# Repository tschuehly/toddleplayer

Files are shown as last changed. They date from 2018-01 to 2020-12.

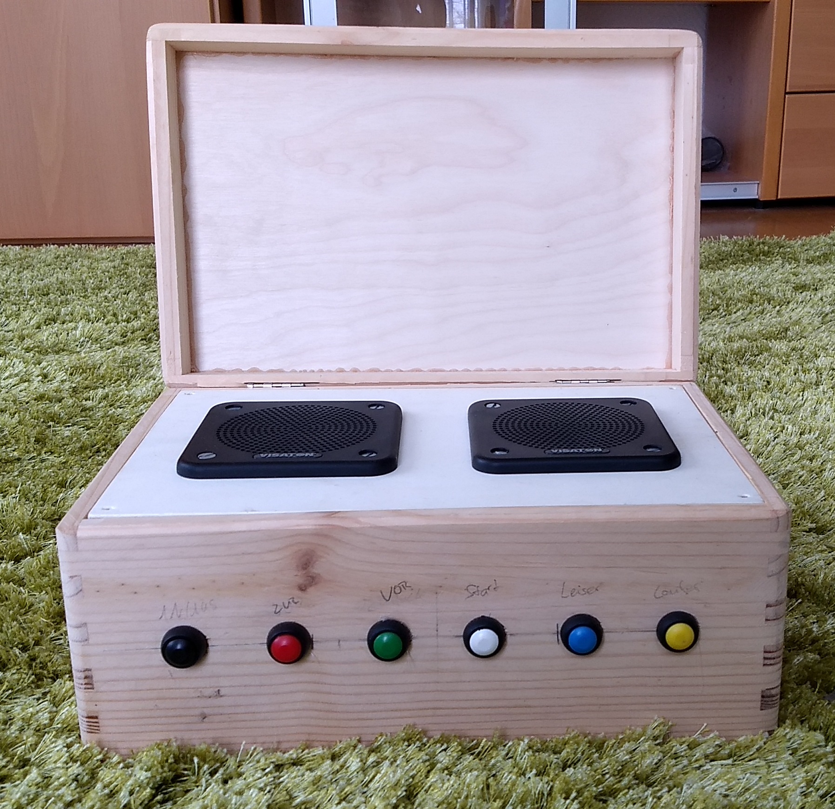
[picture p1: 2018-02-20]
img/front.jpg

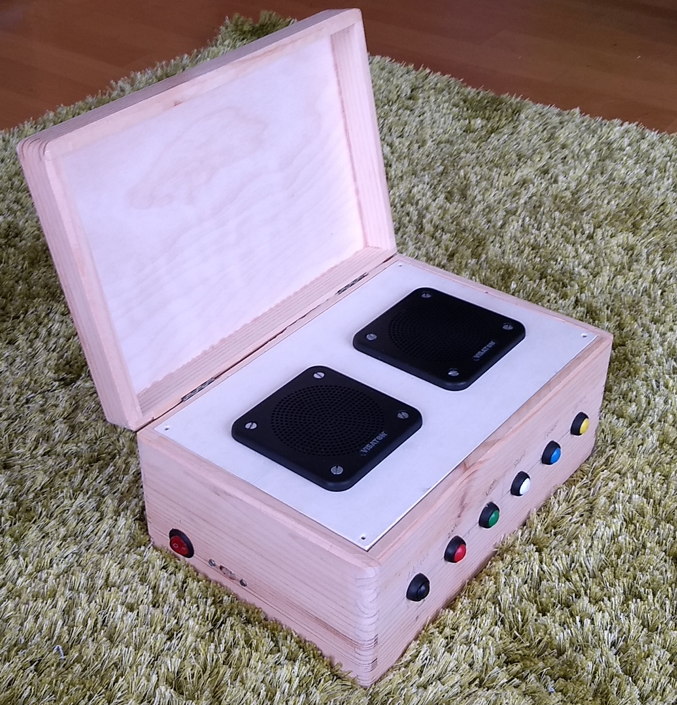
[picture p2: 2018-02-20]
img/side.jpg

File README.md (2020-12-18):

# toddleplayer
toddleplayer is the manual and a bunch of scripts to create an MP3 and Spotify Player controlled through RFID Tags and GPIO Buttons.

## Hardware

Required:

* A [Raspberry Pi](https://www.raspberrypi.org/products/): I'm using a Pi Zero W

* DAC: You can either use a [pHAT DAC 15€](https://shop.pimoroni.com/products/phat-dac)
or a [PCM5102A 3€](https://www.aliexpress.com/item/1Pcs-PCM5102A-DAC-Sound-Card-Board-pHAT-3-5mm-Stereo-Jack-24-Bits-Digital-Audio-Module/32836159429.html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)

* Any kind of casing: [Wooden Box](http://www.ebay.de/itm/ZWEIERGRUPPE-EINFACHES-HOLZ-HOLZKISTE-TRUNK-OHNE-GRIFFE-FUR-SERVIETTEN/152320770330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)

* A few push buttons: [Push Buttons](https://www.ebay.de/itm/152295745935?_trksid=p2060353.m2749.l2649&ssPageName=STRK%3AMEBIDX%3AIT)

* A Digital Audio Amplifier:  [PAM8403](https://www.aliexpress.com/store/product/MCIGICM-SAMIORE-ROBOT-PAM8403-mini-5V-digital-amplifier-board-with-switch-potentiometer-can-be-USB-powered/506373_3290775546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)

* Passive Speakers: [Visaton FR 87](https://www.conrad.de/de/34-zoll-breitband-lautsprecher-chassis-visaton-fr-87-15-w-4-1173601.html)

* A [Powerbank](https://www.amazon.de/LERVING-10000mAh-Powerbank-Ladeger%C3%A4t-Technologie/dp/B00Q2M3AAM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) or some 18650 Li-Ion Cells and a [Power Supply Board](https://www.aliexpress.com/item/5PCS-5V-Step-Up-Power-Supply-Boost-Converter-Module-Lithium-Battery-Charging-Protection-Board-LED-Display/32852290552.html)

* A [USB RFID READER](https://smile.amazon.de/gp/product/B018OYOR3E/ref=oh_aui_detailpage_o03_s00?ie=UTF8&psc=1) and USB OTG cable or a [MFRC-522](https://www.aliexpress.com/store/product/MCIGICM-MFRC-522-RC522-mfrc-522-RFID-RF-IC-card-inductive-module-S50-Fudan-card-key/506373_32905192359.html)

### Wiring

#### PCMA5102A
To wire up the cheaper PCMA5102A breakout board you have to wire like this:

| PCMA | Raspberry |
|---|---|
| VCC  | 5V PIN 2 |
| GND  | GND |
| FLT  | GND |
| DMP  | GND |
| SCL  | GND |
| BCK  | GPIO18 PIN 12 |
| DIN  | GPIO21 PIN 40 |
| LCK  | GPIO19 Pin 35 |
| FMT  | GND |

XMT <–> 10k Resistor <–> 3,3V of the PCM5102A board

#### PAM8403

Then you wire the L ,G and R Pins of the PCMA to the Input Pins of the PAM. You connect the + and - power pins of the pam8403 directly to the 5V of the Raspberry and GND. Then you connect your speakers to rout/lout + and -.

#### pHAT DAC
If you use the pHAT DAC you have to solder it. You can solder all of them or solder them the  [lazy way. ](https://forums.pimoroni.com/t/phat-header-soldering-the-lazy-way/1690)

#### RC-522

| RC522| Raspberry |
|---|---|
| 3.3V | 3.3V PIN 1 |
| RST  | GPIO25 PIN 22 |
| GND  | GND |
| MISO | GPIO9 PIN 21  |
| MOSI | GPIO10 PIN19  |
| SCK  | GPIO11 PIN 23 |
| SDA  | GPIO8 PIN 24  |

## Software

### Pi MusicBox
To create this Player you first have to install Pi Musicbox on your local Raspberry.
You can download the latest image frome here: [RC6](https://github.com/pimusicbox/pimusicbox/releases/tag/v0.7.0RC6)

Burn the image to an SD Card with [Etcher](https://etcher.io/)

1. Put the SD-card into your computer. Ignore the format warning when you're on windows. Open the contents of the 'config' folder of SD-Card in your Finder/Explorer.

2. Open settings.ini and add your Wifi network and password to the file
3. Set 	```enable_ssh = true```

4. Set ```output = hifiberry_dac```

5. Set ```resize_once = true```

You can also set your Spotify and Spotify-Web credentials already.

Then you have to put the SD card in the Raspberry and power it up. You can lookup the IP adress on your router.
To test your wiring connect to the toddleplayer in the webbrowser and run a radiostream unter the tab Streams.

To connect to the Raspberry use your favorite ssh client like [PuTTY](https://www.putty.org/).

The standard user is ```root``` and the password is ```musicbox```.

### First Setup
You have to download the required scripts and unpack them from the latest release.
```
cd ../
wget https://github.com/tschuehly/toddleplayer/releases/download/test/toddleplayer.zip
unzip toddleplayer.zip
rm toddleplayer.zip
cd toddleplayer/
```

### music-cards

If you use a USB RFID Reader continue here. If you use the MFRC-522 continue down below with the RC522_music-cards extension.

Next you have to install python evdev.

```
wget http://dl.piwall.co.uk/python-evdev_0.4.1-1_armhf.deb
dpkg -i python-evdev_0.4.1-1_armhf.deb
```

Then you have to configure it.

```
cd music-cards/
python config.py
```
Select the RFID reader from the inputs. Usually by pressing 0.
### RC522_music-cards

```
sudo nano /boot/config.txt
```
Find this line and remove the '#':
```
#dtparam=spi=on
```
Next, install Python 2.7 dev and gcc using:
```
sudo apt-get update
sudo apt-get install python2.7-dev
sudo apt-get install gcc
```
Then download and install the special SPI tool for python with wget.
```
wget https://github.com/lthiery/SPI-Py/archive/master.zip
unzip master.zip
rm master.zip
cd ./SPI-Py-master
```
then install it by

```
sudo python setup.py install
cd ../
```
Next you have to install python-mpd2 from source here

```
wget https://github.com/Mic92/python-mpd2/archive/master.zip

unzip master.zip
rm master.zip
cd ./python-mpd2-master
python setup.py install
```
### musicbox_gpio script

The easiest way to start the script on startup is to append the following lines to the /opt/musicbox/startup.sh. You have to replace /xxxx/ with either /RC522_music-cards/ or /music-cards/

```
nohup python -u /toddleplayer/gpio_control.py &> /toddleplayer/gpio.log &
echo "started gpio_control.py"
sleep 15
python -u /toddleplayer/xxxx/box.py &> /toddleplayer/box.log &
echo "started box.py"

```

### Configuration

Now you can create as many folders as you want in the /music/ folder and add the RFID tags accordingly

```
python add_card.py
```

Now you can choose either if you want to add a local folder by pressing [L] or a spotify playlist by pressing [S]

then you have to type in the folder you want to associate with the RFID Card
```
file:/music/foldername/
```

To quit you just have to press CTRL + C

### Credit
The toddleplayer is based on the Pi Musicbox Image: https://github.com/pimusicbox/pimusicbox ,

the music-cards mopidy extension which I altered heavily: https://github.com/fsahli/music-cards ,

the RC522_music-cards project:
https://github.com/tschuehly/RC522_music-cards ,
which uses the MFRC522-python library:
https://github.com/mxgxw/MFRC522-python ,

the python-mpd2 library:
https://github.com/Mic92/python-mpd2 .

&#169; Thomas Schühly

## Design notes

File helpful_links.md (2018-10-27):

https://www.wiki.52pi.com/images/c/ca/1.How_to_use_1_GPIO_Pin_to_drive_RaspberryPi_Power-on-off-status_light.pdf
http://www.embeddedpi.com/documentation/gpio/mypi-industrial-raspberry-pi-psu-shutdown-gpio-line
https://blog.sengotta.net/connecting-a-pcm5102a-breakout-board-to-a-raspberry-pi/
https://pimylifeup.com/raspberry-pi-rfid-rc522/

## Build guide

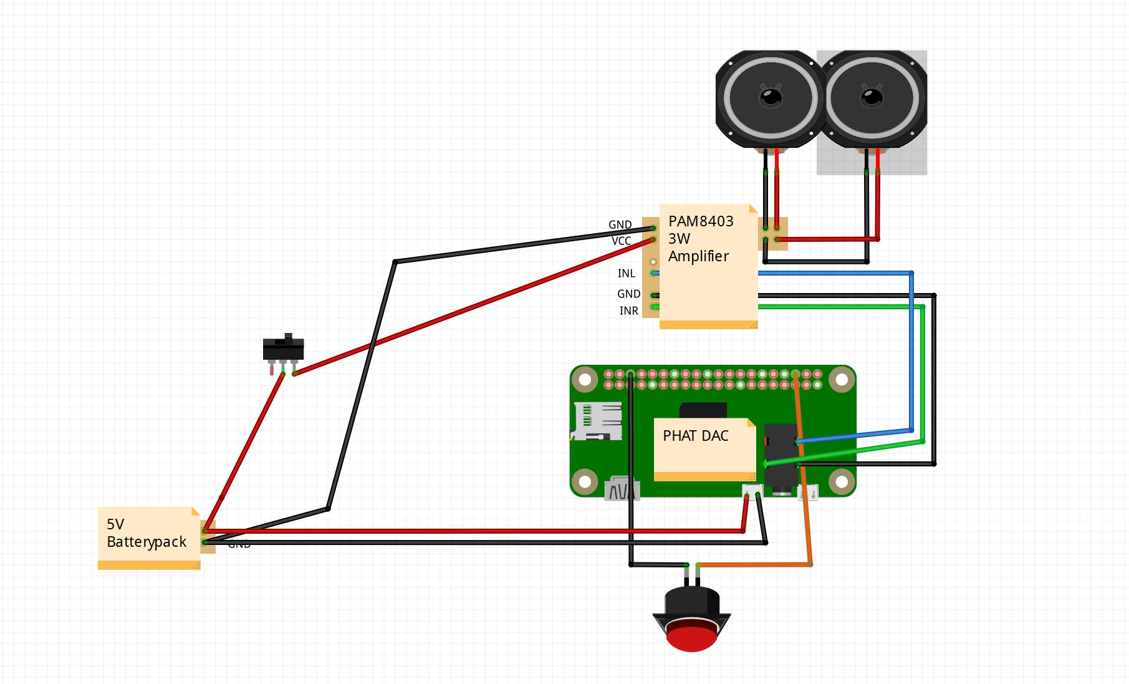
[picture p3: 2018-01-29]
img/toddleplayer_wiring.JPG

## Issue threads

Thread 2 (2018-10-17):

Script just quit

bernie78ger, 2018-10-17:
HI!

When i run the scripts eg (~/toddleplayer/src/RC522_music-cards# sudo python Reader.py) they just quit ...

tschuehly, 2018-10-17:
Hello,

I'm still developing the toddleplayer, especially the RC522 port. Currently I only finished one box with the USB RFID module.  What steps did you follow exactly till now?

tschuehly, 2018-10-20:
You don't actually have to run the other scripts. They are just part of the box.py and add_card.py. At startup you have to start box.py. You have to copy the Spotify URI from an album like this: spotify:album:0c78nsgqX6VfniSNWIxwoD
I'm gonna do a full installation of a musicbox this week and update the installation manual.

bernie78ger, 2018-10-21:
HI there .. thank you in advance.
i guess this would help beginners.

i found the reason for another problem i had.
i found out that some cards are easyer to read than others.
some cards will need more than one attempt to get the full card uid.
the problem was that add_card.py received sometimes an empty id. and i thought those cards were not working properly.

so i altered the code in reader.py and now even those cards work.
the loop waits for an valid id and not just for a found card.

def readCard(MIFAREReader):
        while True:
                # Scan for cards
                (status,TagType) = MIFAREReader.MFRC522_Request(MIFAREReader.PICC_REQIDL)
                # If a card is found
                if status == MIFAREReader.MI_OK:
                        print "Card detected"
                        # Get the UID of the card
                        (status,uid) = MIFAREReader.MFRC522_Anticoll()
                        if uid:
                                #print uid
                                card = ''.join(str(i) for i in uid)
                                print "ID:"
                                print card
                                if len(card)>3:
                                        return card
                                        break

tschuehly, 2018-10-21:
Ok thank you very much for your contribution. I didn't test the RFC Reader much yet.

tschuehly, 2018-10-27:
@bernie78ger

I've updated the readme to make it more clear what to do. Could you either make a pull request with the updated reader.py or copy the text with proper indentation so I can try the code myself?

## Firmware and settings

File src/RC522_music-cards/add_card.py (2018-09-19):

#from readtest import *
from CardList import CardList
import RPi.GPIO as GPIO
import MFRC522
from Reader import readCard
import time
cardList = CardList()
MIFAREReader = MFRC522.MFRC522()

while True:
		print 'Place the card in the reader or press CTRL+C to quit'
		card = readCard(MIFAREReader)
		print card
		localOrSpotify=raw_input('Press [S] for Spotify Playlist [L] for local folder').lower()
		if localOrSpotify in "s":
			plist=raw_input('Specify Spotify URI, q to quit')
			if plist=="q":
				break
		if localOrSpotify in "l":
			plist=raw_input('Specify local folder path like this: file:/music/Card*/, q to quit')
			if plist=="q":
				break
		cardList.addPlaylist(card, plist)
print "Exiting"

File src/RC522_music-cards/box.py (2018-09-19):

#!/usr/bin/env python
from mpd import MPDClient
import re
from CardList import CardList
import sys
import os
import RPi.GPIO as GPIO
import MFRC522
from Reader import readCard
import time

# Capture SIGINT for cleanup when the script is aborted
def end_read(signal,frame):
    global continue_reading
    print "Ctrl+C captured, ending read."
    continue_reading = False
    GPIO.cleanup()



def connectMPD():
	try:
		client = MPDClient()               # create client object
		client.timeout = 200               # network timeout in seconds (floats allowed), default: None
		client.idletimeout = None
		print "Connecting..."
		client.connect("localhost", 6600)
		print "Connected!"
		return client
	except:
		print 'Could not connect to MPD server'

def playlist(client,plist):
	try:
		plist2 = re.sub('file:','',plist)
		print plist
		for root,dirs,files in os.walk(plist2):
			for filename in files:
				filename = plist + filename
				print filename
				client.add(filename)
		return plist
	except Exception as e:
		print(e)

def play(client, plist):
	try:
		client.stop()
		client.clear()
		if re.search('file', plist):
			playlist(client,plist)
			client.shuffle()
		if re.search('spotify',plist):
			client.add(plist)
			client.shuffle()
		client.play()
	except:
		print 'Could not play playlist %s' % plist


MIFAREReader = MFRC522.MFRC522()
cardList = CardList()

print 'Ready: place a card on top of the reader'

while True:
	try:
		card = readCard(MIFAREReader)
		print 'Read card', card

		plist = cardList.getPlaylist(card)
		if plist != '':
			print 'Playlist', plist
			client = connectMPD()
			if plist=='pause':
				client.pause()
			else:
				play(client, plist)
			client.close()
		time.sleep(1)
	except KeyboardInterrupt:
		GPIO.cleanup()
		sys.exit(0)
	except:
		pass

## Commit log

2018-01-29 Added Fritzing Wire and updated README.md
2018-01-29 Added Wiring Image
    [toddleplayer.fzz]
